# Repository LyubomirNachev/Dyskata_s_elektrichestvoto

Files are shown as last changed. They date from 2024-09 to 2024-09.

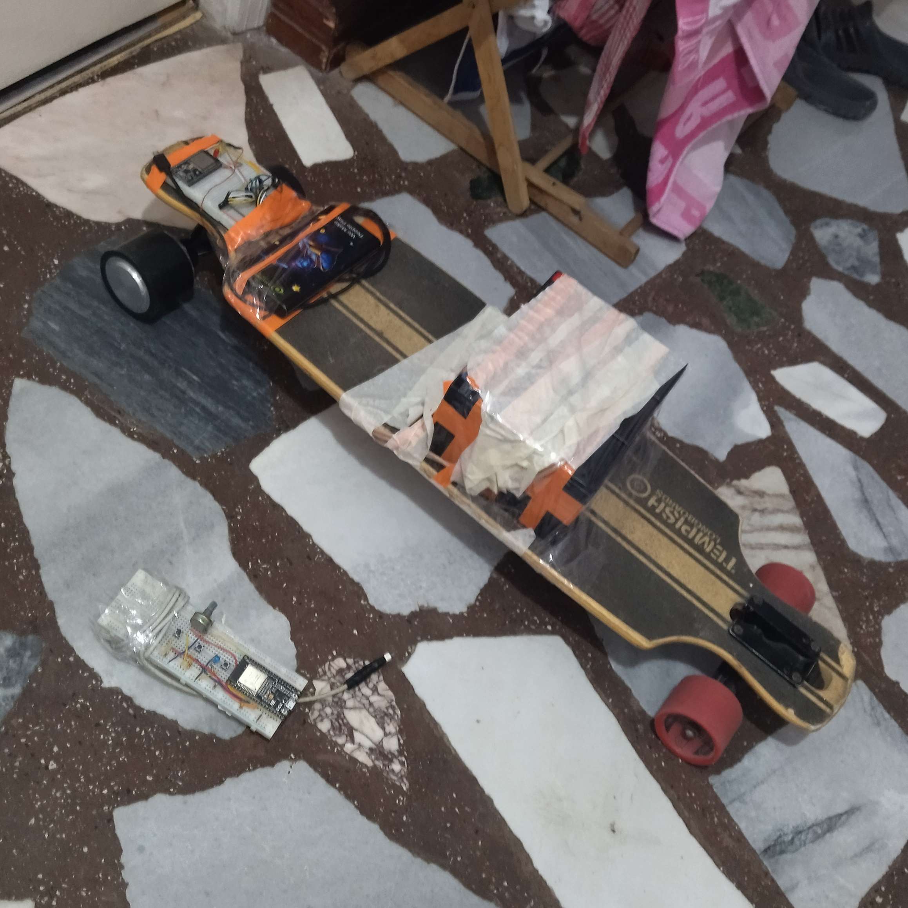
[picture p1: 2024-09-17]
mark_v1.jpg

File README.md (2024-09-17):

# Dyskata_s_elektrichestvoto
Electric Skateboard
I use BLE for the communication between the ESP32 on the board configured as a host and the ESP32 on the remote configured as a server.

## Main Components:
* 2x ESP32 Dev kits
* 3x 12V9Ah Lead Acid Batteries
* 2x ZS-X11H v2 motor controllers
* 1x Wheel skateboard kit with 2 brushless motors
* 1x skateboard
* 100x Nerves :)

## Future features(I hope):
* Printed PCB 
* 3D model for the remote 
* 3D model for mounting and encapsulating the components on the board 
* Speedometer 
* Odometer 
* Charge indication 
* Interface for easier charging 
* GPS location for prevention from theft

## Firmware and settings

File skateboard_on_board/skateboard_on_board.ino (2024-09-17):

#include <BLEDevice.h>

static BLEUUID SERVICE_UUID("63b5a895-bd3d-4d34-b360-607d92fb7f13");
static BLEUUID BRAKE_CHAR_UUID("38ee12c0-b3ff-40ec-a7fa-0c0307ad7032");
static BLEUUID STOP_CHAR_UUID("fb8cfd3d-260a-4e90-a55c-2ab854de8d0a");
static BLEUUID DIR_CHAR_UUID("4a5d63a1-1fae-493d-bf72-2b923b0756ee");
static BLEUUID SPEED_CHAR_UUID("81010060-39d8-494e-a11c-f071fa06fbbb");

#define STOP_PIN 25
#define BRAKE_PIN 32
#define DIR_PIN 33
#define SPEED_PIN 26 // brown cable
#define SPEED_MONITOR 27 //blue cable
#define POT_PIN 14

#define bleServerName "ESP32_Skateboard_contoller"
static BLEAdvertisedDevice *myDevice;

static boolean doConnect = false;
static boolean connected = false;
static boolean reconnect = false;

static BLEAddress *pServerAddress;
static BLERemoteCharacteristic* pBrakeCharacteristic;
static BLERemoteCharacteristic* pStopCharacteristic;
static BLERemoteCharacteristic* pDirCharacteristic;
static BLERemoteCharacteristic* pSpeedCharacteristic;

const uint8_t notificationOn[] = {0x1, 0x0, 0x0, 0x0};

uint8_t* Brake_info;
uint8_t* Stop_info;
uint8_t* Dir_info;
uint32_t* Speed_info;

boolean newBrake_info = false;
boolean newStop_info = false;
boolean newDir_info = false;
boolean newSpeed_info = false;

const int PWM_FREQ = 19000;     
const int PWM_RESOLUTION = 12; 
const int MAX_DUTY_CYCLE = (int)(pow(2, PWM_RESOLUTION) - 1); 

bool connectToServer(BLEAddress pAddress);

class MyClientCallback : public BLEClientCallbacks {
  void onConnect(BLEClient *pclient) {}

  void onDisconnect(BLEClient *pclient) {
    connected = false;
    reconnect = true;
    Serial.println("onDisconnect");
  }
};

bool connectToServer(BLEAddress pAddress) {
  Serial.print("Forming a connection to ");

  BLEClient *pClient = BLEDevice::createClient();
  Serial.println(" - Created client");

  pClient->setClientCallbacks(new MyClientCallback());

  pClient->connect(pAddress);  
  Serial.println(" - Connected to server");

  BLERemoteService *pRemoteService = pClient->getService(SERVICE_UUID);
  if (pRemoteService == nullptr) {
    Serial.print("Failed to find our service UUID: ");
    pClient->disconnect();
    return false;
  }
  Serial.println(" - Found our service");

  pBrakeCharacteristic = pRemoteService->getCharacteristic(BRAKE_CHAR_UUID);
  pStopCharacteristic = pRemoteService->getCharacteristic(STOP_CHAR_UUID);
  pDirCharacteristic = pRemoteService->getCharacteristic(DIR_CHAR_UUID);
  pSpeedCharacteristic = pRemoteService->getCharacteristic(SPEED_CHAR_UUID);
  if (pBrakeCharacteristic == nullptr || pStopCharacteristic == nullptr || pDirCharacteristic == nullptr || pSpeedCharacteristic == nullptr) {
    Serial.print("Failed to find our characteristic UUID: ");
    pClient->disconnect();
    return false;
  }
  Serial.println(" - Found our characteristic");

  pBrakeCharacteristic->registerForNotify(BrakeNotifyCallback);
  pStopCharacteristic->registerForNotify(StopNotifyCallback);
  pDirCharacteristic->registerForNotify(DirNotifyCallback);
  pSpeedCharacteristic->registerForNotify(SpeedNotifyCallback);

  connected = true;
  return true;
}

class MyAdvertisedDeviceCallbacks: public BLEAdvertisedDeviceCallbacks {
  void onResult(BLEAdvertisedDevice advertisedDevice) {
    if (advertisedDevice.getName() == bleServerName) { 
      advertisedDevice.getScan()->stop(); 
      pServerAddress = new BLEAddress(advertisedDevice.getAddress()); 
      doConnect = true; 
      Serial.println("Device found. Connecting!");
    }
  }
};

static void BrakeNotifyCallback(BLERemoteCharacteristic* pBLERemoteCharacteristic, 
                                        uint8_t* pData, size_t length, bool isNotify) {
  Brake_info = pData;
  newBrake_info = true;
}
static void StopNotifyCallback(BLERemoteCharacteristic* pBLERemoteCharacteristic, 
                                    uint8_t* pData, size_t length, bool isNotify) {
  Stop_info = pData;
  newStop_info = true;
}
static void DirNotifyCallback(BLERemoteCharacteristic* pBLERemoteCharacteristic, 
                                    uint8_t* pData, size_t length, bool isNotify) {
  Dir_info = pData;
  newDir_info = true;
}
static void SpeedNotifyCallback(BLERemoteCharacteristic* pBLERemoteCharacteristic, 
                                    uint8_t* pData, size_t length, bool isNotify) {
  Speed_info = (uint32_t*)pData;
  newSpeed_info = true;
}

void setup() {
  Serial.begin(9600); 
  Serial.println("Starting Arduino BLE Client application...");
  BLEDevice::init("");

  BLEScan* pBLEScan = BLEDevice::getScan();
  pBLEScan->setAdvertisedDeviceCallbacks(new MyAdvertisedDeviceCallbacks());
  pBLEScan->setActiveScan(true);
  pBLEScan->start(30);


  pinMode(STOP_PIN, OUTPUT); // stop
  pinMode(BRAKE_PIN, OUTPUT); //brake
  pinMode(DIR_PIN, OUTPUT);  //dir
  pinMode(SPEED_PIN, OUTPUT); //pwm signal
  pinMode(SPEED_MONITOR, INPUT); //rpm out
  ledcAttach(SPEED_PIN, PWM_FREQ, PWM_RESOLUTION);
}

void loop() {
  if (doConnect == true || reconnect == true) {
    if (connectToServer(*pServerAddress)) {
      Serial.println("We are now connected to the BLE Server.");

      pBrakeCharacteristic->writeValue((uint8_t*)notificationOn, 2, true);
      pStopCharacteristic->writeValue((uint8_t*)notificationOn, 2, true);
      pDirCharacteristic->writeValue((uint8_t*)notificationOn, 2, true);
      pSpeedCharacteristic->writeValue((uint8_t*)notificationOn, 2, true);
      connected = true;
      reconnect = false;
    } else {
      Serial.println("We have failed to connect to the server; Restart your device to scan for nearby BLE server again.");
    }
    doConnect = false;
  }else{
    
  }
  if (newStop_info){
    newStop_info = false;
    Serial.print("Stop:");
    Serial.println(*Stop_info);
    digitalWrite(STOP_PIN, *Stop_info); 
  }else if(newBrake_info){
    newBrake_info=false;
    Serial.print("Brake:");
    Serial.println(*Brake_info);
    digitalWrite(BRAKE_PIN, *Brake_info); 
  }else if(newDir_info){
    newDir_info=false;
    Serial.print("Dir:");
    Serial.println(*Dir_info);
    digitalWrite(DIR_PIN, *Dir_info); 
  }else if(newSpeed_info){
    newSpeed_info=false;
    Serial.print("Speed:");
    Serial.println(*Speed_info);
    ledcWrite(SPEED_PIN, *Speed_info);
  }
}

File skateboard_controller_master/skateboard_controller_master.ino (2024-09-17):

#include <BLEDevice.h>
#include <BLEUtils.h>
#include <BLEServer.h>
#include <BLE2902.h>
#include <BLE2901.h>

#define SERVICE_UUID        "63b5a895-bd3d-4d34-b360-607d92fb7f13"
#define BRAKE_CHAR_UUID     "38ee12c0-b3ff-40ec-a7fa-0c0307ad7032"
#define STOP_CHAR_UUID      "fb8cfd3d-260a-4e90-a55c-2ab854de8d0a"
#define DIR_CHAR_UUID       "4a5d63a1-1fae-493d-bf72-2b923b0756ee"
#define SPEED_CHAR_UUID     "81010060-39d8-494e-a11c-f071fa06fbbb"

BLEServer *pServer = NULL;
BLECharacteristic *pCharacteristicBrake = NULL;
BLECharacteristic *pCharacteristicStop = NULL;
BLECharacteristic *pCharacteristicDir = NULL;
BLECharacteristic *pCharacteristicSpeed = NULL;

#define BRAKE_PIN 27
#define STOP_PIN 25
#define DIR_PIN 35
#define SPEED_PIN 32
#define LED1_PIN 14

String serverName = "ESP32_Skateboard_contoller";
bool deviceConnected = false;

volatile int flag_brake = 0;
volatile int flag_stop = 0;
volatile int flag_dir = 0;
void IRAM_ATTR toggle_brake();
void IRAM_ATTR toggle_stop();
void IRAM_ATTR toggle_dir();

const int PWM_FREQ = 19000;     
const int PWM_RESOLUTION = 12; 
const int MAX_DUTY_CYCLE = (int)(pow(2, PWM_RESOLUTION) - 1); 

class MyServerCallbacks: public BLEServerCallbacks {
  void onConnect(BLEServer* pServer) {
    deviceConnected = true;
    Serial.println("Connected Succesfully!");
    digitalWrite(LED1_PIN, HIGH); 
  };
  void onDisconnect(BLEServer* pServer) {
    deviceConnected = false;
    Serial.println("Device disconnected!!!"); 
  }
};

void setup() {
  pinMode(BRAKE_PIN, INPUT);
  pinMode(STOP_PIN, INPUT);
  pinMode(DIR_PIN, INPUT);
  pinMode(SPEED_PIN, INPUT);
  pinMode(LED1_PIN, OUTPUT);
  attachInterrupt(BRAKE_PIN, toggle_brake, RISING);
  attachInterrupt(STOP_PIN, toggle_stop, RISING);
  attachInterrupt(DIR_PIN, toggle_dir, RISING);

  Serial.begin(115200);
  Serial.println("BLE is intilized, waiting for connection.");

  BLEDevice::init(serverName);
  pServer = BLEDevice::createServer();
  pServer->setCallbacks(new MyServerCallbacks());
  BLEService *pService = pServer->createService(SERVICE_UUID);
  pCharacteristicBrake = pService->createCharacteristic(
                                         BRAKE_CHAR_UUID,
                                         BLECharacteristic::PROPERTY_READ | BLECharacteristic::PROPERTY_WRITE | BLECharacteristic::PROPERTY_NOTIFY | BLECharacteristic::PROPERTY_INDICATE
                                       );
  pCharacteristicStop = pService->createCharacteristic(
                                         STOP_CHAR_UUID,
                                         BLECharacteristic::PROPERTY_READ | BLECharacteristic::PROPERTY_WRITE | BLECharacteristic::PROPERTY_NOTIFY | BLECharacteristic::PROPERTY_INDICATE
                                       );     
  pCharacteristicDir = pService->createCharacteristic(
                                         DIR_CHAR_UUID,
                                         BLECharacteristic::PROPERTY_READ | BLECharacteristic::PROPERTY_WRITE | BLECharacteristic::PROPERTY_NOTIFY | BLECharacteristic::PROPERTY_INDICATE
                                       );   
  pCharacteristicSpeed = pService->createCharacteristic(
                                         SPEED_CHAR_UUID,
                                         BLECharacteristic::PROPERTY_READ | BLECharacteristic::PROPERTY_WRITE | BLECharacteristic::PROPERTY_NOTIFY | BLECharacteristic::PROPERTY_INDICATE
                                       );  
                                                                                                
  pService->start();
  pCharacteristicBrake->setValue((uint8_t *)&flag_brake, 1); 
  pCharacteristicBrake->notify(); 
  pCharacteristicStop->setValue((uint8_t *)&flag_stop, 1); 
  pCharacteristicStop->notify();    
  pCharacteristicDir->setValue((uint8_t *)&flag_dir, 1); 
  pCharacteristicDir->notify();   
  BLEAdvertising *pAdvertising = BLEDevice::getAdvertising();
  pAdvertising->addServiceUUID(SERVICE_UUID);
  pAdvertising->setScanResponse(false);
  pAdvertising->setMinPreferred(0x0);
  BLEDevice::startAdvertising();
  Serial.println("Characteristics defined! Now you can read it in your phone!");
}

void IRAM_ATTR toggle_brake(){
 if (digitalRead(BRAKE_PIN) == HIGH && flag_brake == 0){
    flag_brake = 1;
    pCharacteristicBrake->setValue((uint8_t *)&flag_brake, 1);
    pCharacteristicBrake->notify();
    
    Serial.println("on");

  }else if(digitalRead(BRAKE_PIN) == HIGH && flag_brake == 1){
    flag_brake = 0;
    Serial.println("off");
    pCharacteristicBrake->setValue((uint8_t *)&flag_brake, 1); 
    pCharacteristicBrake->notify();
  }
}

void IRAM_ATTR toggle_stop(){
 if (digitalRead(STOP_PIN) == HIGH && flag_stop == 0){
    flag_stop = 1;
    pCharacteristicStop->setValue((uint8_t *)&flag_stop, 1); 
    pCharacteristicStop->notify();
  }else if(digitalRead(STOP_PIN) == HIGH && flag_stop == 1){
    flag_stop = 0;
    pCharacteristicStop->setValue((uint8_t *)&flag_stop, 1); 
    pCharacteristicStop->notify();

  }
}

void IRAM_ATTR toggle_dir(){
 if (digitalRead(DIR_PIN) == HIGH && flag_dir == 0){
    flag_dir = 1;
    pCharacteristicDir->setValue((uint8_t *)&flag_dir, 1); 
    pCharacteristicDir->notify();
  }else if(digitalRead(DIR_PIN) == HIGH && flag_dir == 1){
    flag_dir = 0;
    pCharacteristicDir->setValue((uint8_t *)&flag_dir, 1); 
    pCharacteristicDir->notify();
  }
}


void speed(){
    int pot_value = analogRead(SPEED_PIN);
    pot_value = map(pot_value, 0, 4095, 0, MAX_DUTY_CYCLE); 
    Serial.print("Decimal:");
    Serial.print(pot_value);
    Serial.print("Hex:");
    Serial.println(pot_value, HEX);

    pCharacteristicSpeed->setValue((uint8_t *)&pot_value, 4); 
    pCharacteristicSpeed->notify();
    delay(50);
}

void loop() {
  if (deviceConnected){
    speed();
  }else{
    digitalWrite(LED1_PIN, LOW);
    delay(100); 
    digitalWrite(LED1_PIN, HIGH); 
    delay(100); 
    BLEDevice::startAdvertising();
  }
}

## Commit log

2024-07-01 First version of the code and schematics
    Not everything is finished
    [Electro_dyska.kicad_pcb, Electro_dyska.kicad_sch]
2024-09-17 Working
    The onboard device configuration is fully working, configured as a ble client with added reconnect feature.
2024-09-17 Updated schematics
    Not finished
    [Electro_dyska.kicad_sch, Elektro_kontroler.kicad_pcb, Elektro_kontroler.kicad_sch]
